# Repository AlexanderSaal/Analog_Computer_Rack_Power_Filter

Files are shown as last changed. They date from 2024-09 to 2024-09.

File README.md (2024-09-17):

# Simple and Cost Effective Low Ripple Power Filter
---

A Ripple filter for the power supply of a modular **Analog Computer** in Eurorack format. The design goal is to be simple in part count and assembly while being cost effective and maintaining low ripple output.\
The filter is designed for a **+15V/-15V input power supply** and a **+12V/-12V output**.

The filter is devided into two parts, for the positive and negative supply voltage. In a first step the voltage is filteres in a **capacitance multiplier**, supplied by a second order **RC low-pass filter**. The output is then put through a second stage a **linear voltage regulator**. In simulations in *falstadts online circuit simulator* and *LTSpice*, the resulting output voltage should have a **voltage ripple in the lower mV range**, depending on the input powwer supply.

For an explaination on how a capacitance multiplier works, see [1].

---
## PCB render

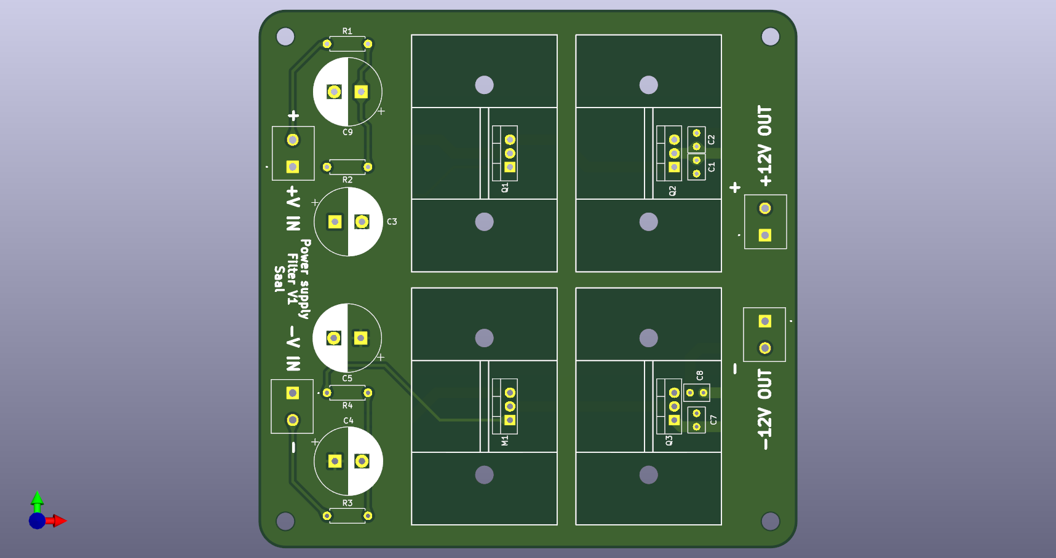
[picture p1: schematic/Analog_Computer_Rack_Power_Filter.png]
schematic Image of the PCB


---
## Schematic

Schematic if the power supply filter. \
As a first step the power is routed through a capacitance multiplier with a second order RC low pass filter. The corner frequency here is set to around 10 Hz.

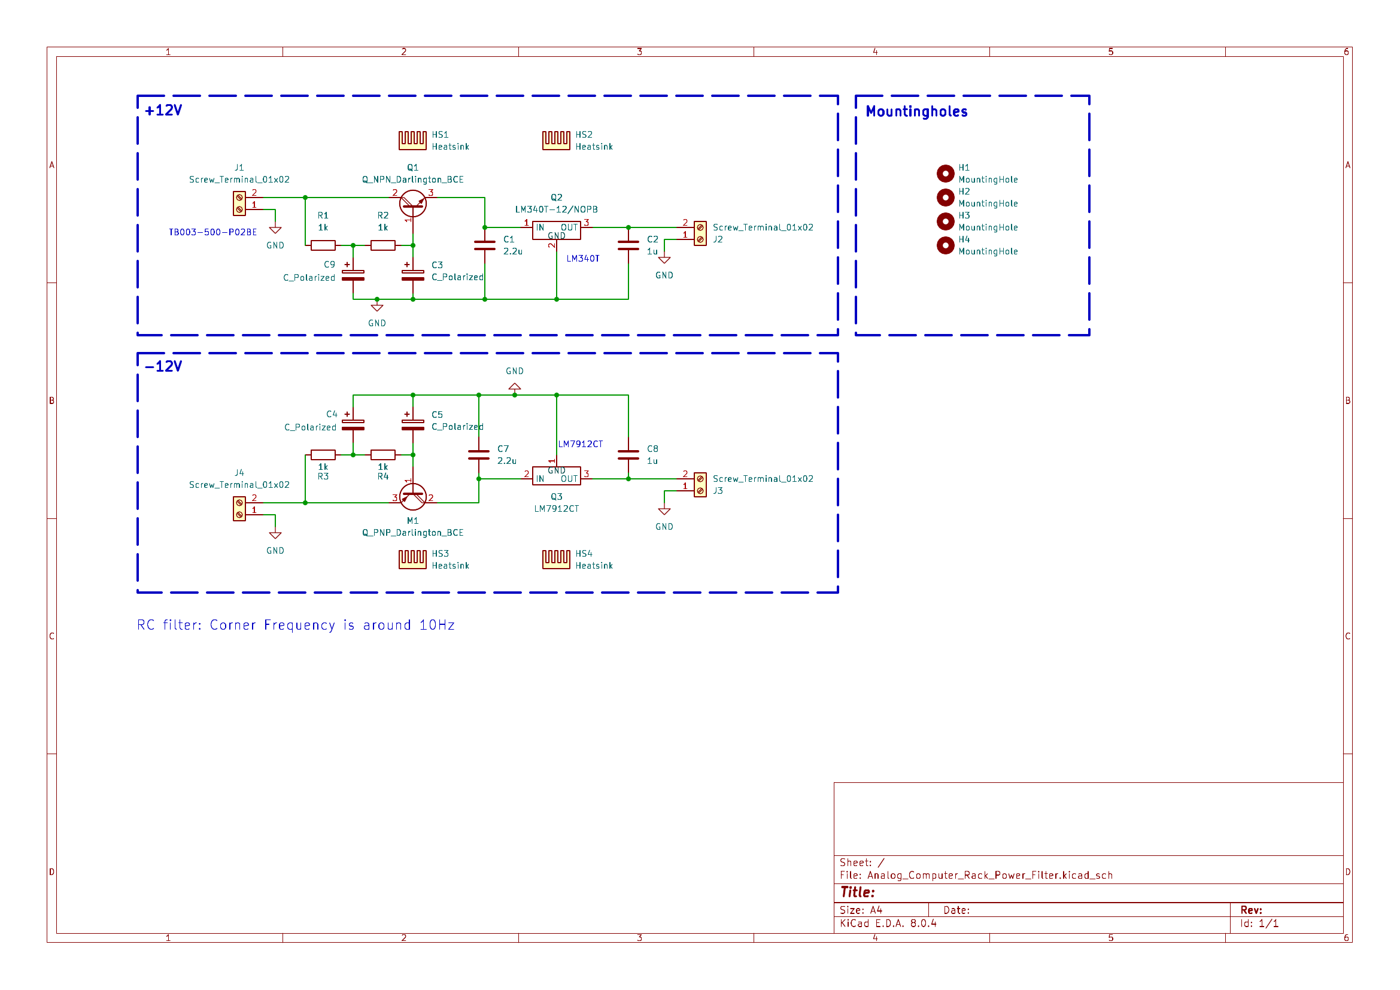
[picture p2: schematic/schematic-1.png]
schematic Power connection, current limiting and mounting holes


---
## Components

**<u>Darlingtons:</u>**\
[MJF122G](https://www.digikey.de/de/products/detail/onsemi/MJF122G/919531) \
[MJF127G](https://www.digikey.de/de/products/detail/onsemi/MJF127G/919532)

**<u>Linear Regulators:</u>**\
12V 3A:\
[MIC29300-12WT](https://www.digikey.de/de/products/detail/microchip-technology/MIC29300-12WT/771587)

-12V 1.5A:\
[LM7912CT/NOPB](https://www.digikey.de/de/products/detail/texas-instruments/LM7912CT-NOPB/6355)

-12V 1.8A:\
[LM2990T-12/NOPB](https://www.digikey.de/de/products/detail/texas-instruments/LM2990T-12-NOPB/182373)

12V 1.5A:\
[LM340T-12/NOPB](https://www.digikey.de/de/products/detail/texas-instruments/LM340T-12-NOPB/6233)

**<u>TO-220 Heatsinks:</u>**\
[Boyd Laconia 513002B02500G](https://www.digikey.de/de/products/detail/boyd-laconia-llc/513002B02500G/1625590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)\
[Boyd Laconia 530002B02500G](https://www.digikey.de/de/products/detail/boyd-laconia-llc/530002B02500G/1216384)\
[Boyd Laconia 529802B02500G](https://www.digikey.de/de/products/detail/boyd-laconia-llc/529802B02500G/1216357)

**<u>Isolator:</u>**\
[THERM PAD](https://www.digikey.de/de/products/detail/boyd-laconia-llc/56-77-11G/1625385)

**<u>Screws:</u>**\
[M3,5x0,6 Nylon](https://www.digikey.de/de/products/detail/essentra-components/50M035060D012/11639017)\
[M3,5 Nut Nylon](https://www.digikey.de/de/products/detail/essentra-components/04M035060HN/9677097)

**<u>Base Power supply:</u>**\
[PD-2515](https://www.digikey.de/de/products/detail/mean-well-usa-inc/PD-2515/7705635)

**<u>Filter Capacitors:</u>**\
[UBY2A161MHL](https://www.digikey.de/de/products/detail/nichicon/UBY2A161MHL/9452708)
[0.22u CL31B224KBFNNNE](https://www.digikey.de/de/products/detail/samsung-electro-mechanics/CL31B224KBFNNNE/3886764)
[0.1u 1206B104K500CT](https://www.digikey.de/de/products/detail/walsin-technology-corporation/1206B104K500CT/9355102)

**<u>Output Linear Regulator Capacitors:</u>**\
[2.2u Typ1](https://www.digikey.de/de/products/detail/kemet/C320C225K5N5TA91707301/14318938)\
[1u Type1](https://www.digikey.de/de/products/detail/kemet/C320C105K5N5TA/14681443)\
[2.2u Type2](https://www.digikey.de/de/products/detail/tdk-corporation/FA14X7R1H225KRU06/5865806)\
[1u Type2](https://www.digikey.de/de/products/detail/tdk-corporation/FG18X5R1H105KRT06/5802871)

**<u>Filter Resistor:</u>**\
[MFR50SFTE52-100R](https://www.digikey.de/de/products/detail/yageo/MFR50SFTE52-100R/9151030)

---
## Sources

 [1] [capacitance Multiplier](https://sound-au.com/articles/cap-multiplier.htm
)

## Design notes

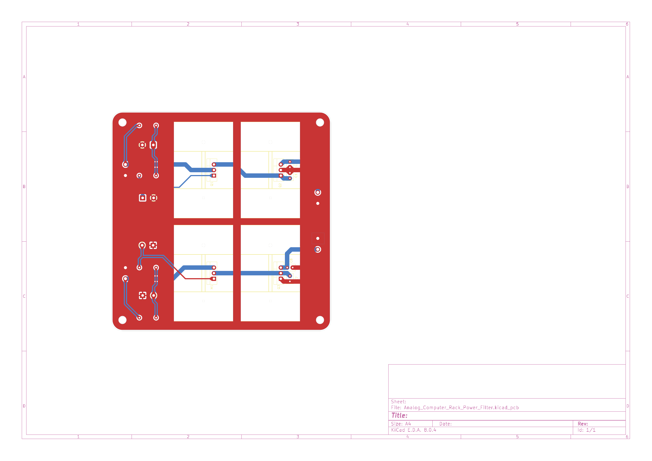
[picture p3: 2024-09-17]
schematic/PCB-1.png

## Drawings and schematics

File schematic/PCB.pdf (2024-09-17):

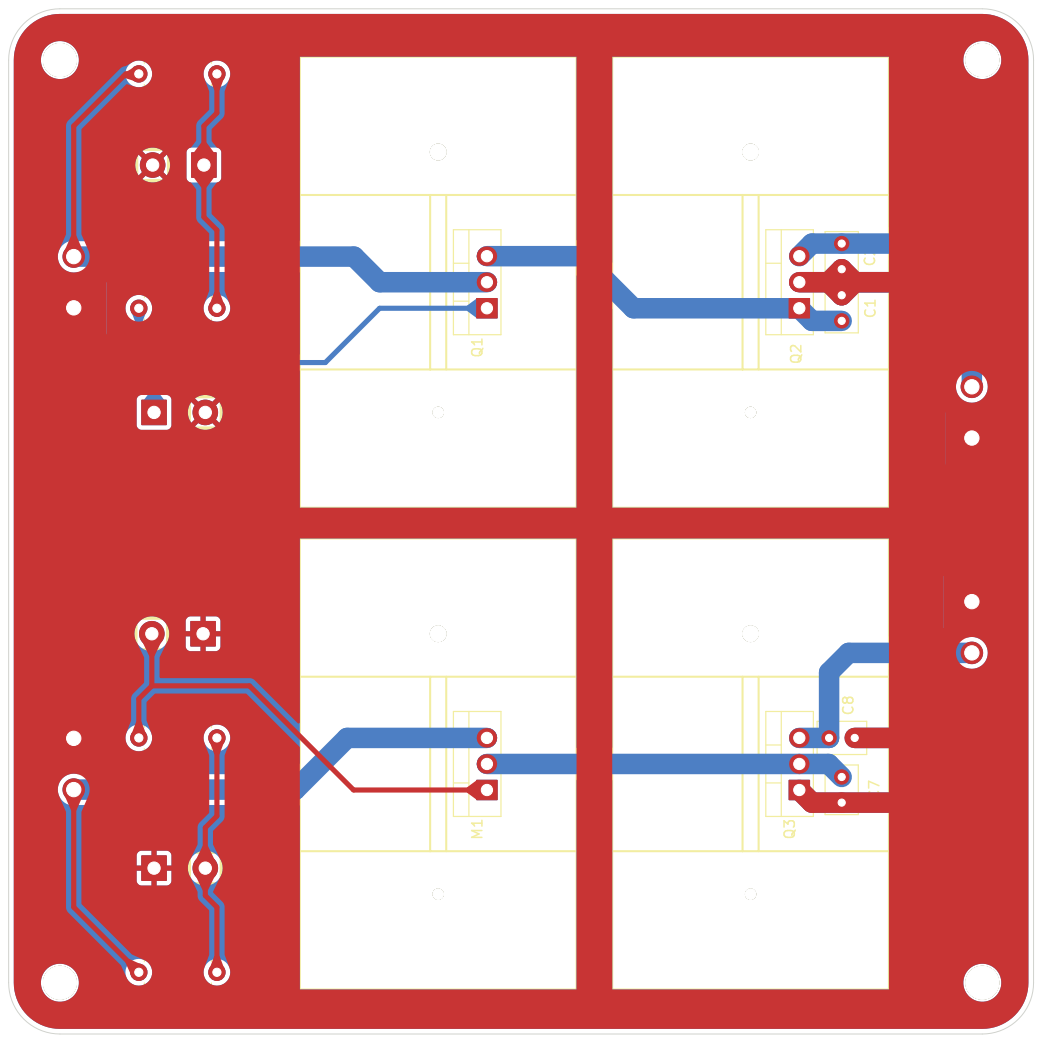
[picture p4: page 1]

Id: 1/1 Title: File: Analog_Computer_Rack_Power_Filter.kicad_pcb Sheet: +V IN

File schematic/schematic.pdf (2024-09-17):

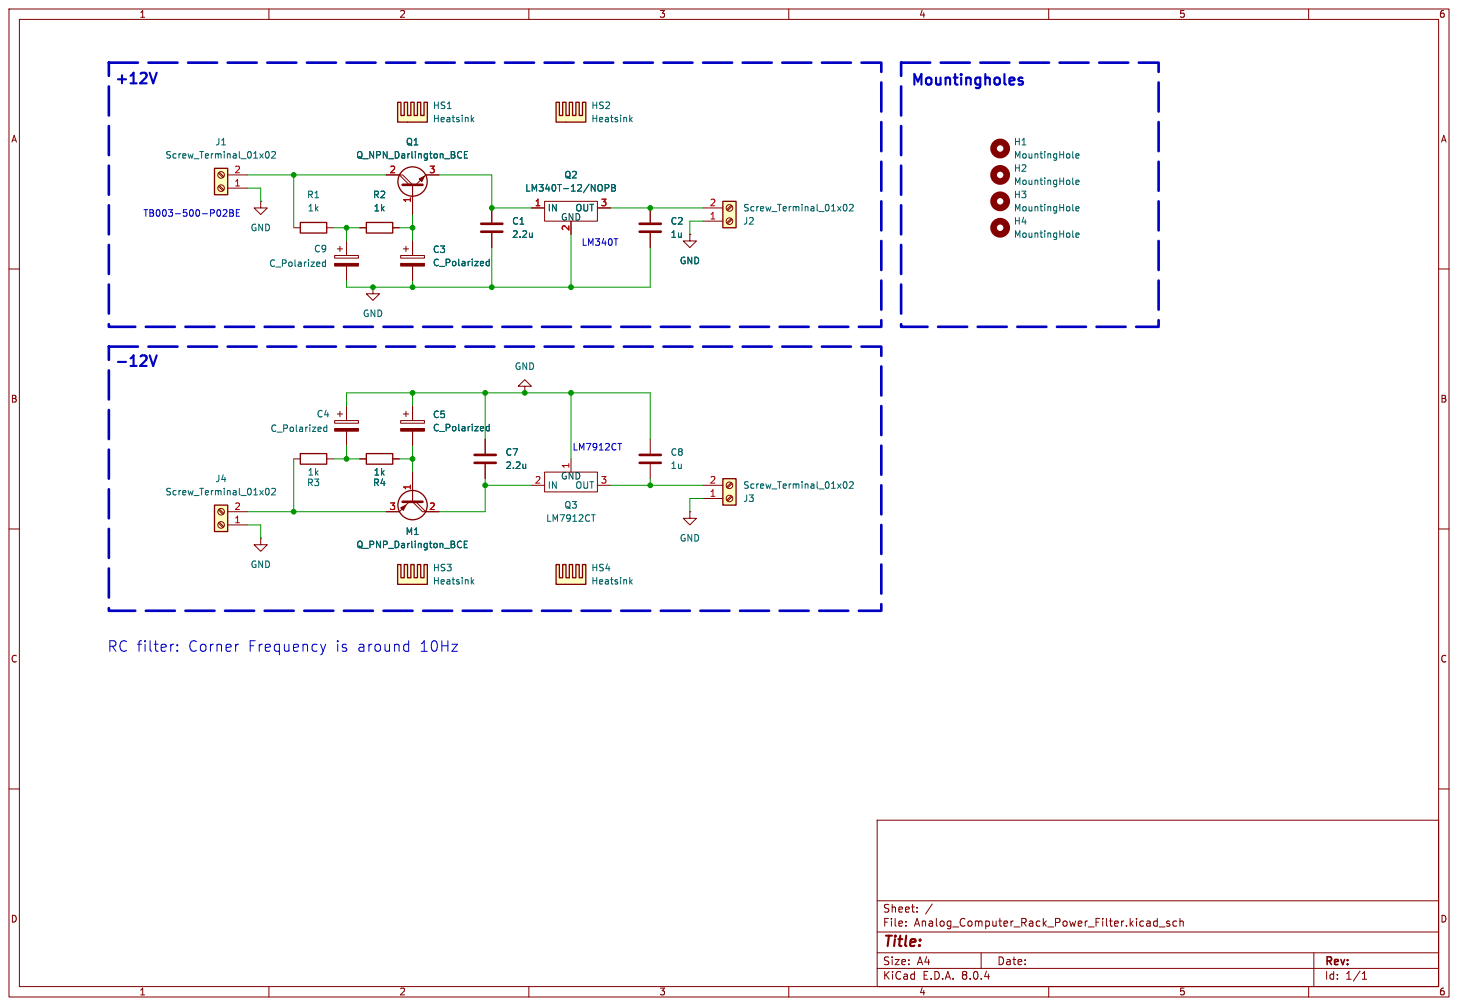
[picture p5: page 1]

H1 MountingHole H3 MountingHole H4 MountingHole HS1 Heatsink 1

Id: 1/1 Title: File: Analog_Computer_Rack_Power_Filter.kicad_sch Sheet: /

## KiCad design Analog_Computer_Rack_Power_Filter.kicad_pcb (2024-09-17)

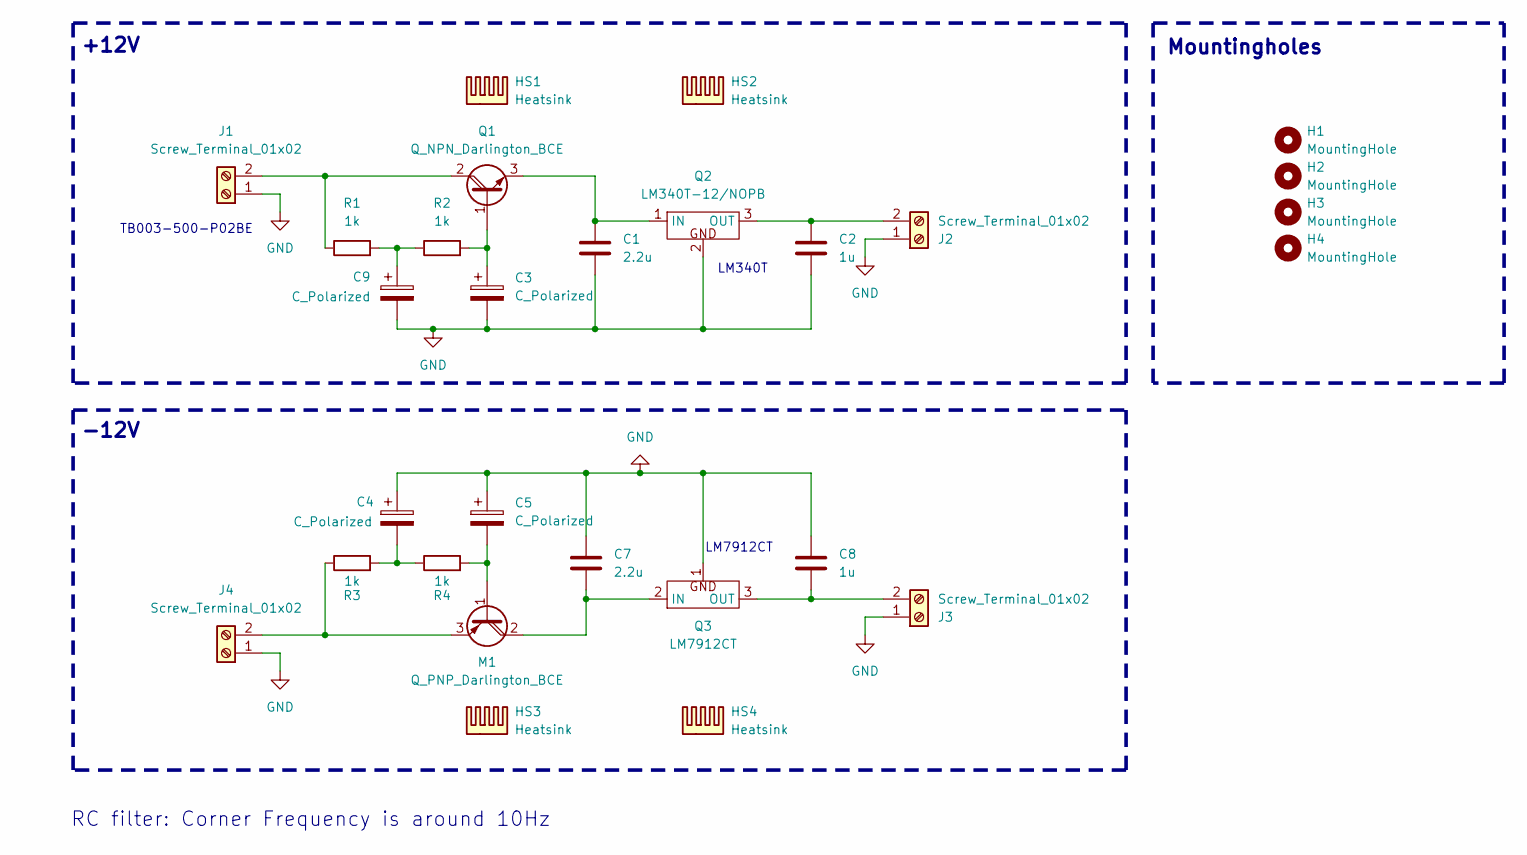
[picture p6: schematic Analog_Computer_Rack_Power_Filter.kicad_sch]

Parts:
C1, C7: 2.2u; C_Rect_L4.6mm_W3.0mm_P2.50mm_MKS02_FKP02
C2, C8: 1u; C_Rect_L4.6mm_W3.0mm_P2.50mm_MKS02_FKP02
C3, C4, C5, C9: C_Polarized; CP_Radial_D12.5mm_P5.00mm
H1, H2, H3, H4: MountingHole; MountingHole_3.2mm_M3_DIN965
HS1, HS2, HS3, HS4: Heatsink; Boyd Laconia, 529802B02500G, HEATSINK
J1, J2, J3, J4: Screw_Terminal_01x02; TerminalBlock_TB003-500-P02BE
M1: Q_PNP_Darlington_BCE; TO-220-3_Vertical
Q1: Q_NPN_Darlington_BCE; TO-220-3_Vertical
Q2: LM340T-12/NOPB; TO-220-3_Vertical
Q3: LM7912CT; TO-220-3_Vertical
R1, R2, R3, R4: 1k; R_Axial_DIN0207_L6.3mm_D2.5mm_P7.62mm_Horizontal

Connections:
GND: C1.2, C2.2, C3.2, C4.1, C5.1, C7.1, C8.1, C9.2, J1.1, J2.1, J3.1, J4.1, Q2.2, Q3.1
unnamed: C4.2, R3.2, R4.1
unnamed: C9.1, R1.2, R2.1
unnamed: J1.2, Q1.2 (C), R1.1
unnamed: C2.1, J2.2, Q2.3 (OUT)
unnamed: C8.2, J3.2, Q3.3 (OUT)
unnamed: J4.2, M1.3 (E), R3.1
unnamed: C5.2, M1.1 (B), R4.2
unnamed: C7.2, M1.2 (C), Q3.2 (IN)
unnamed: C3.1, Q1.1 (B), R2.2
unnamed: C1.1, Q1.3 (E), Q2.1 (IN)

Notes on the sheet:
+12V
-12V
LM7912CT
Mountingholes
RC filter: Corner Frequency is around 10Hz
LM340T
TB003-500-P02BE

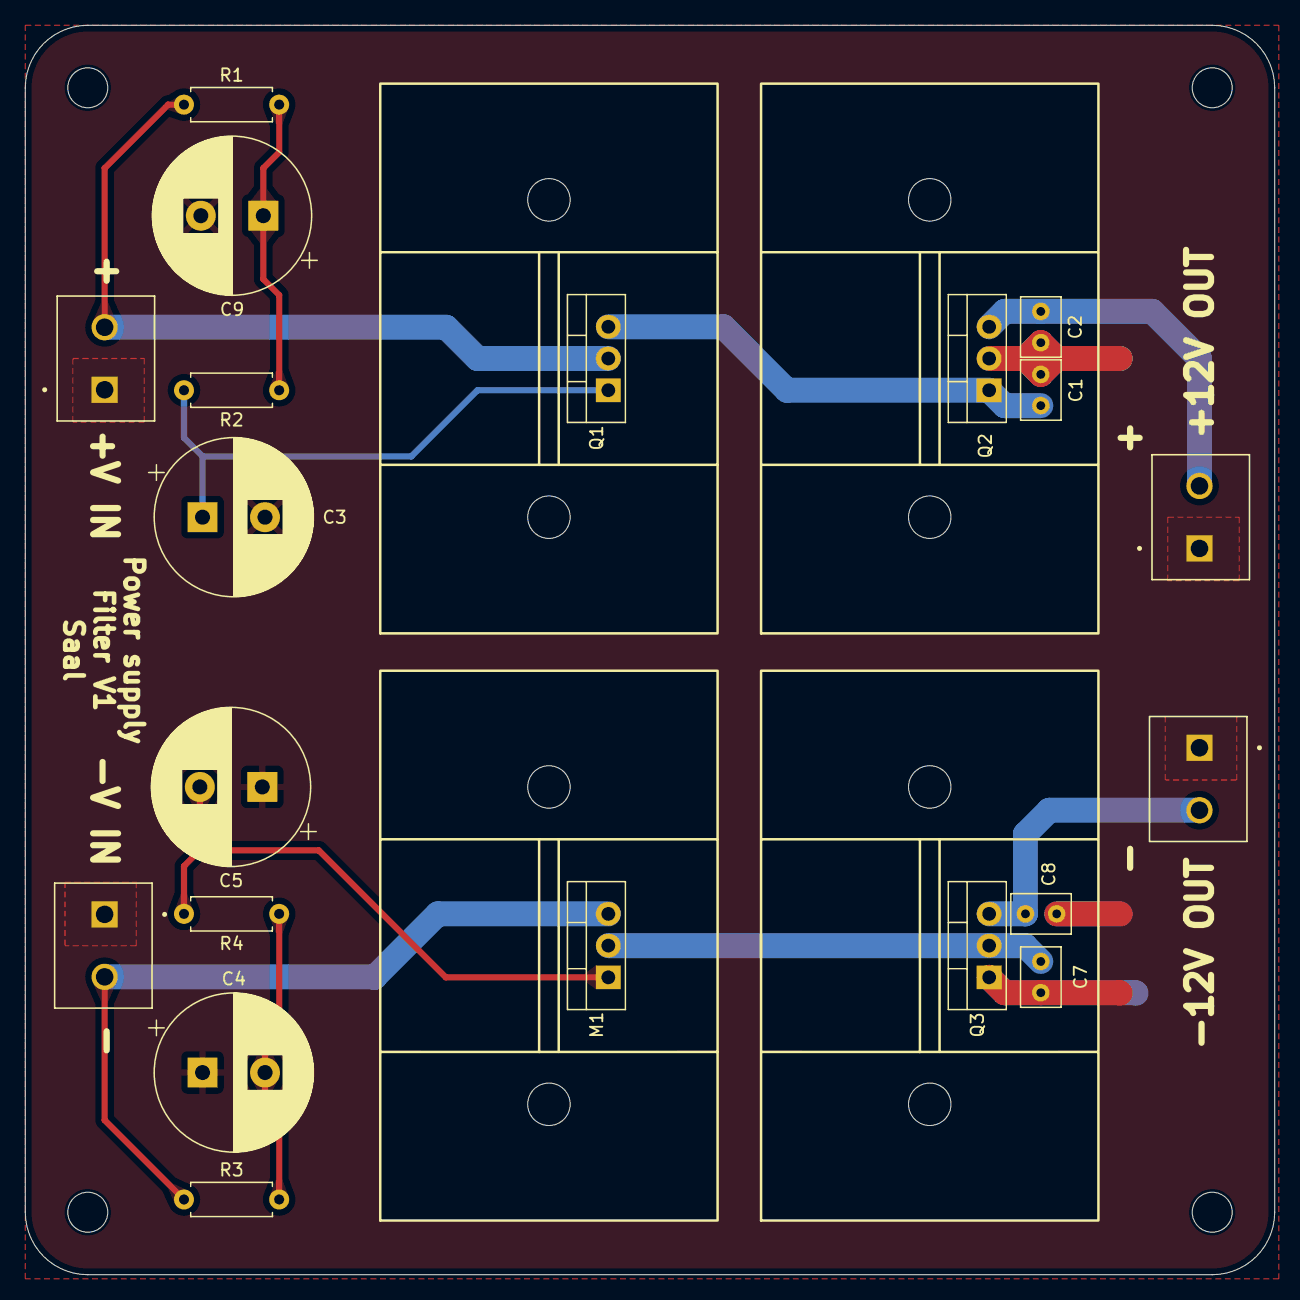
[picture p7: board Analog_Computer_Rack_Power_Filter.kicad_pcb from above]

Board: 2 copper layers, 100.0 x 100.0 mm, 28 parts (0 on the bottom side), 11 nets.
